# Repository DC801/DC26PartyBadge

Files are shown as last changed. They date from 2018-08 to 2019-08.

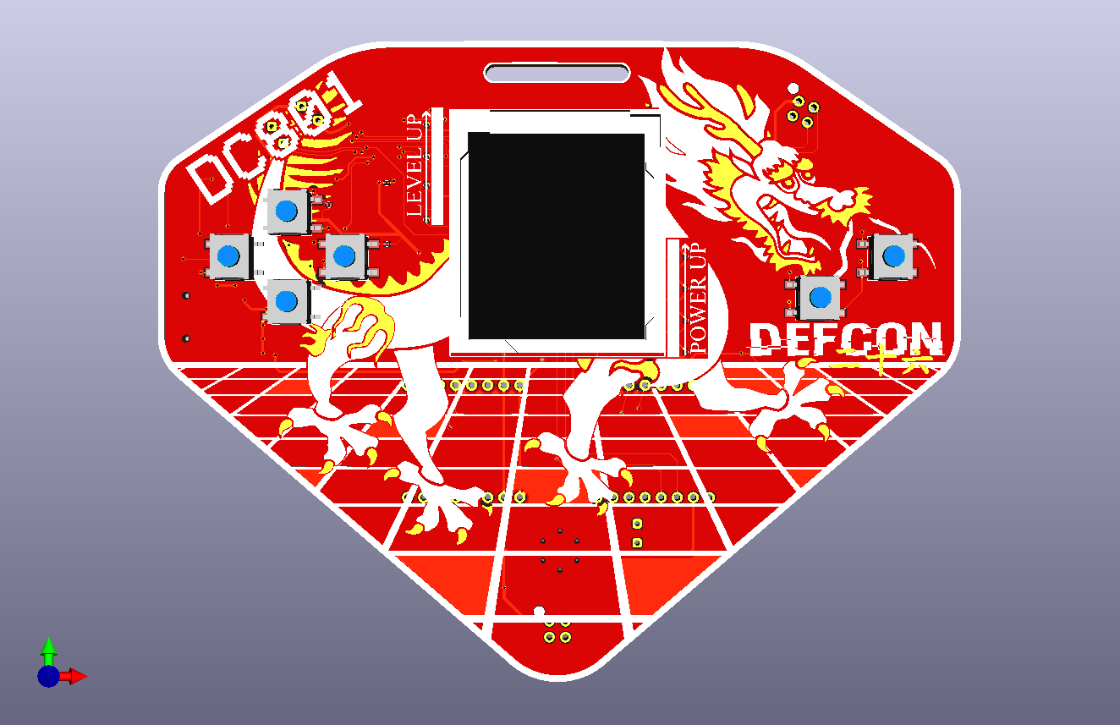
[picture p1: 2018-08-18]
Hardware/images/Dragon-ProtoFinal-Front.png

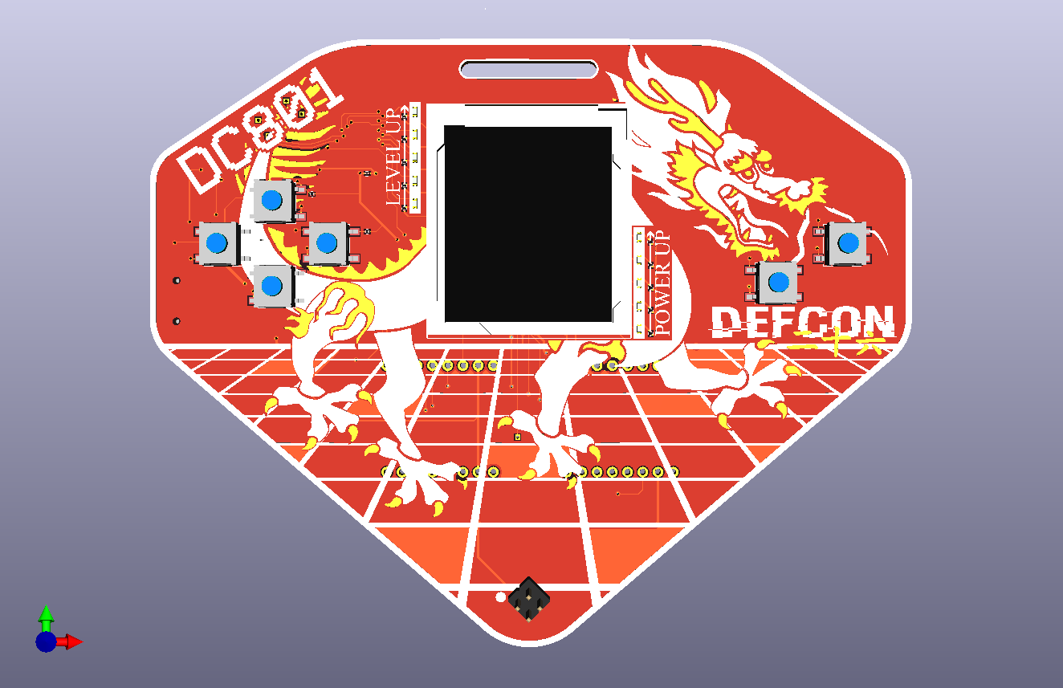
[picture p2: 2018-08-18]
Hardware/images/DragonMockupFront1.png

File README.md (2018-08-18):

# DC801 DC26 Party Badge
Party badge and BLE hardware board

# Hardware
 - **Rigado BMD-300** Bluetooth low energy based on a Nordic nRF52832
   - 16MHz ARM® Cortex™ M4F CPU, 512kB of flash memory, 64kB RAM
   - [https://www.rigado.com/product/bmd-300/](https://www.rigado.com/product/bmd-300/)
 ***
 - **Lots of I/O**
   - Speaker
   - 6 buttons
   - One hidden button
   - SPI LCD screen
   - Selected pin breakouts
   - JTAG interface
   - Micro USB
   - microSD card
   - 2 SAO connectors
   - 2 minibadges
 ***
 - A MCP73831 LiPo battery charger
 - Kickass silkscreen

Board design is in Kicad

See the [Hardware](/Hardware) directory for more info, schematics and etc

# SD Card

Format your SD card as FAT32 and copy the contents of [SD_Card](SD_Card) into it

# Software
 - Environment is GNU ARM GCC with your choice of IDE (I used CLion)
 - Need a J-Link Segger JTAG programmer
 - Uses the softdevice s132

See the [Software](/Software) directory for more info

# What's it do?

Awesome **things**, that's what!  See the [Software](Software) directory for more information.

# More info

Follow [@rushan_ee](http://twitter.com/rushan_ee) or [@hamster](http://twitter.com/hamster) for updates

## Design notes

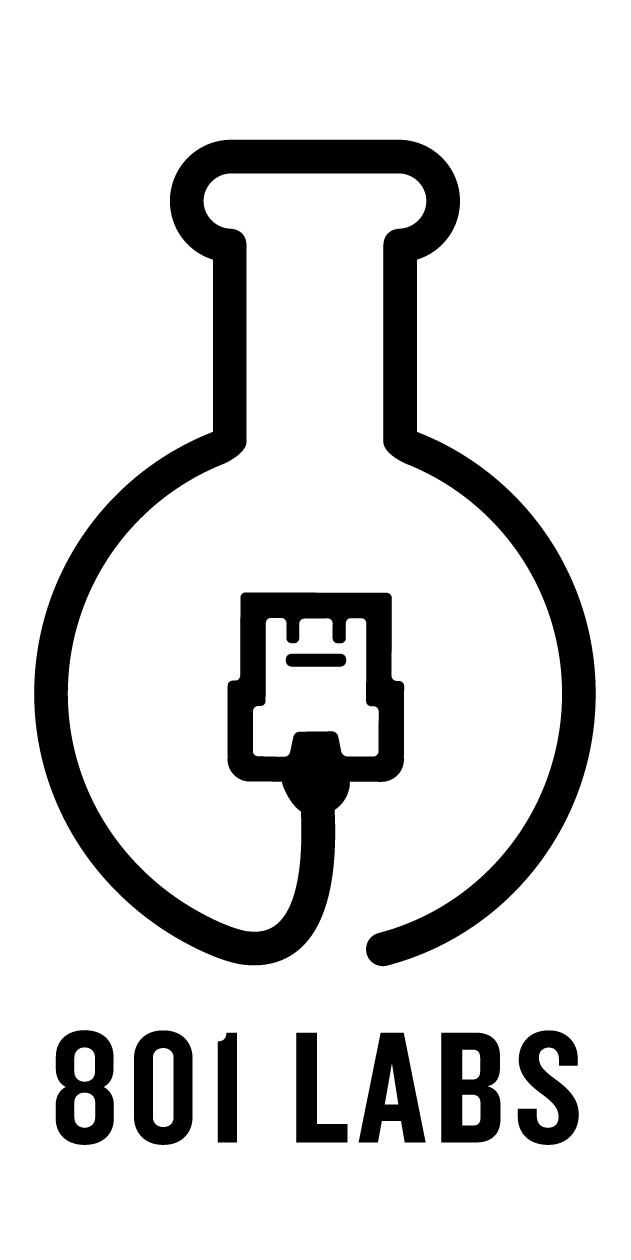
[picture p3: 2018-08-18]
Hardware/images/801LABS-01.png

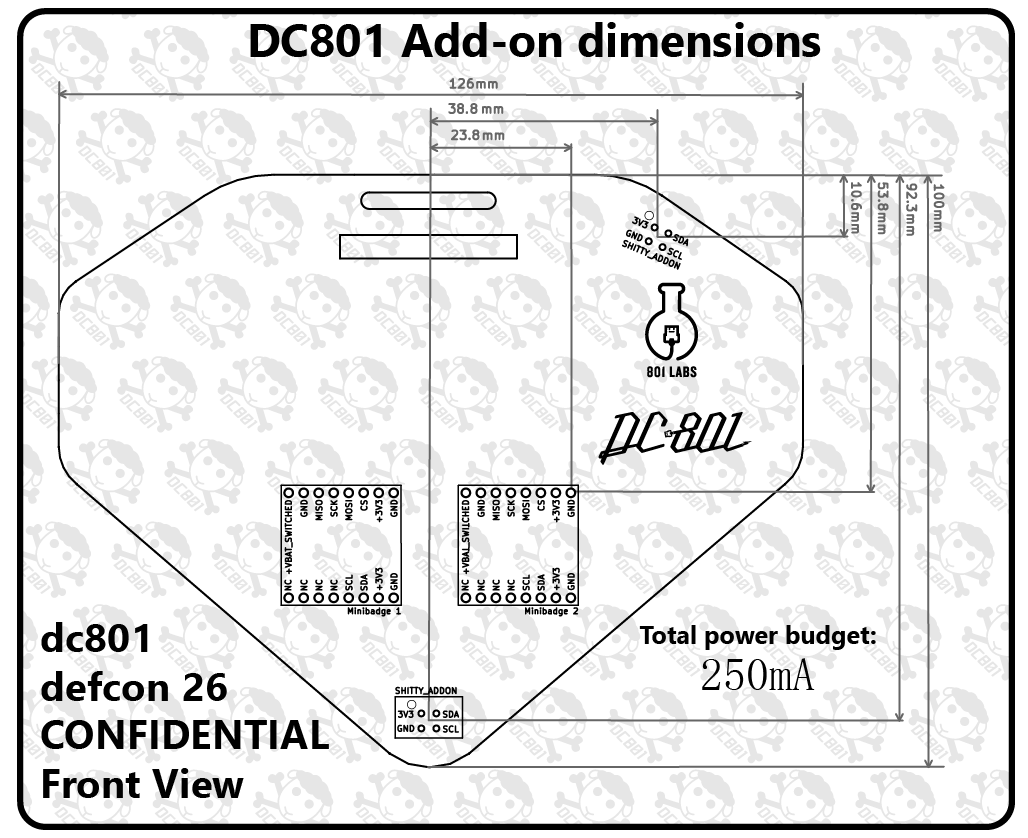
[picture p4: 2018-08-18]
Hardware/images/svg/dc801-dc26-addon-dimensions-01.png

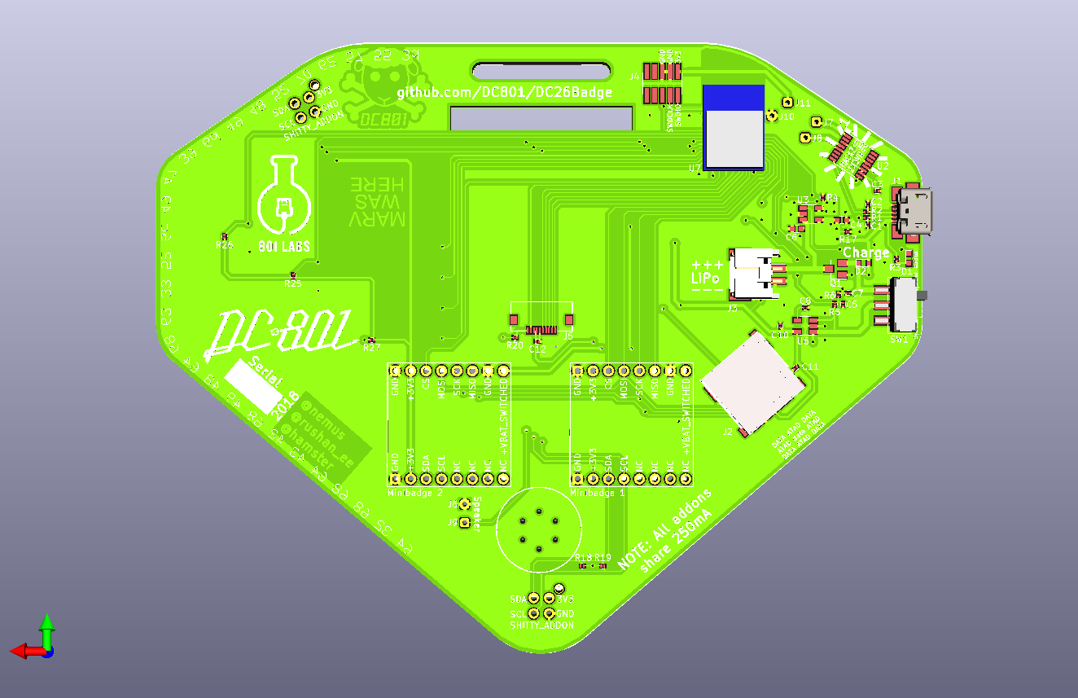
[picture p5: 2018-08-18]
Hardware/images/DragonBoardBack-Final.png

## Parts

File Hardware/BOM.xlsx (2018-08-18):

Ref Des | Description | Mfg Part # | Package | Supplier | Supplier Part # | QTY per badge | Cost ea | Cost badge | Min Qty | Total Needed | Total Cost
U1,U4 - DNS | Minibadge socket
U5 - DNS | Shitty Addon socket
U3 | LiPo charger | MCP73831T-2ACI/OT | SOT-23-5 | Digikey | MCP73831T-2ACI/OTCT-ND | 1 | 0.4452 | 0.4452 |  | 400 | 178.08
U6 | 3.3V Reg 400mA | TPS73633DBVT | SOT95P280X145-5N | Digikey | 296-15819-1-ND | 1 | 1.518 | 1.518 | 250 | 400 | 607.2
U7 | Rigado BMD-300 | BMD-300 | BMD-300 | Digikey | 1604-1006-2-ND | 1 | 7.0623 | 7.0623 | 1000 | 400 | 2824.92
U2 - DNS | FTDI USB to Serial - DNS | FT230XS | SSOP-16 | Digikey | 768-1135-1-ND | 0 | 1.71 | 0 |  | 0 | 0
C5 | 1nF | GRM033R71C102KA01D | 0201 | Digikey | 490-6147-1-ND | 1 | 0.0117 | 0.0117 |  | 400 | 4.68
C3,C7,C8,C9,C10,C11,C12 | 0.1uF Cap | GRM033R60J104KE19D | 0201 | Digikey | 490-3167-1-ND | 5 | 0.0156 | 0.078 |  | 2000 | 31.2
C1,C2 | 47pF Cap | C0201C470J4GAC7867 | 0201 | Digikey | 399-14861-1-ND | 2 | 0.055 | 0.11 |  | 800 | 44
C4,C6 | 4.7uF Cap | C0603C104K9RAC7867 | 0603 | Digikey | 399-15351-1-ND | 2 | 0.1161 | 0.2322 |  | 800 | 92.88
D2 | Schottky diode | SD0603S040S0R2 | 0603 | Digikey | 478-7798-1-ND | 1 | 0.15572 | 0.15572 |  | 400 | 62.288
D1,D3,D4 | Red LED | SML-D12V1WT86 | 0603 | Digikey | SML-D12V1WT86CT-ND | 4 | 0.04007 | 0.16028 | 1000 | 1600 | 64.112
D5,D6,D11 | Yellow LED | SML-D12Y1WT86 | 0603 | Digikey | SML-D12Y1WT86DKR-ND | 3 | 0.04007 | 0.12021 | 1000 | 1200 | 48.084
D8,D9,D10 | Green LED | SML-D12M1WT86 | 0603 | Digikey | SML-D12M1WT86DKR-ND | 4 | 0.04007 | 0.16028 | 1000 | 1600 | 64.112
Q1 | FDN360P | FDN360P | SuperSOT-3 | Digikey | FDN360PCT-ND | 1 | 0.2943 | 0.2943 |  | 400 | 117.72
R17,R21,R22,R23,R24,R25,R26 | 10k resistor | RMCF0201JG10K0 | 0201 | Digikey | RMCF0201JG10K0CT-ND | 7 | 0.0086 | 0.0602 |  | 2800 | 24.08
R1,R2 | 27R resistor | RMCF0201FT27R0 | 0201 | Digikey | RMCF0201FT27R0CT-ND | 2 | 0.0114 | 0.0228 |  | 800 | 9.12
R3 | 470R resistor | RMCF0201JT470R | 0201 | Digikey | RMCF0201JT470RCT-ND | 1 | 0.0086 | 0.0086 |  | 400 | 3.44
R4 | 2k resistor | RMCF0201JT2K00 | 0201 | Digikey | RMCF0201JT2K00CT-ND | 1 | 0.0158 | 0.0158 |  | 400 | 6.32
R7,R8,R9,R10,R12,R13,R14,R15 | 75R resistor | RC0201JR-0775RL | 0201 | Digikey | YAG2929CT-ND | 10 | 0.0132 | 0.132 |  | 4000 | 52.8
R18,R19 | 4.7k resistor | RMCF0201JT4K70 | 0201 | Digikey | RMCF0201JT4K70CT-ND | 2 | 0.0158 | 0.0316 |  | 800 | 12.64
R27 | 10M resistor | RMCF0201JT10M0 | 0201 | Digikey | RMCF0201JT10M0CT-ND | 1 | 0.0086 | 0.0086 |  | 400 | 3.44
R20 | 33R resistor | RMCF0201FT33R0 | 0201 | Digikey | RMCF0201FT33R0CT-ND | 1 | 0.0114 | 0.0114 |  | 400 | 4.56
R5 | 806k resistor | RMCF0201FT806K | 0201 | Digikey | RMCF0201FT806KCT-ND | 1 | 0.0222 | 0.0222 |  | 400 | 8.88
R6 | 2M resistor | RC0201JR-072ML | 0201 | Digikey | YAG2885CT-ND | 1 | 0.0132 | 0.0132 |  | 400 | 5.28
J3 | JST 2mm male | S2B-PH-SM4-TB(LF)(SN) |  | Digikey | 455-1749-1-ND | 1 |  | 0 |  | 400 | 0
J2 | MicroSD socket | 114-00841-68 |  | Digikey | 114-00841-68-1-ND | 1 | 1.05336 | 1.05336 |  | 400 | 421.344
J1 | Micro USB | 10118192-0001LF |  | Digikey | 609-4613-1-ND | 1 | 0.27444 | 0.27444 |  | 400 | 109.776
J4 | JTAG, dual row 1.27mm | 3220-10-0300-00 |  | Digikey | 1175-1629-ND | 1 | 0.437 | 0.437 | 100 | 400 | 174.8
J5 | FFC/FPC LCD connector | XF2L-1035-1A |  | Digikey | Z5306CT-ND | 1 | 0.9751 | 0.9751 | 100 | 400 | 390.04
SW1 | Power Switch | JS102011SAQN |  | Digikey | 401-1999-1-ND | 1 | 0.43692 | 0.43692 |  | 400 | 174.768
SW2,SW3,SW4,SW5,SW6,SW7 | Pushbuttons | PTS645SM43SMTR92 LFS |  | Digikey | CKN9112TR-ND | 6 | 0.08614 | 0.51684 | 1000 | 2400 | 206.736
SW8 - DNS | Capacitive button |  |  |  |  | 0 | 0 | 0 |  | 0 | 0
Speaker - DNS | 8 ohm speaker | SP-1504 |  | Digikey | 433-1106-ND | 1 | 1.232 | 1.232 |  | 400 | 492.8
LCD - DNS | CFAF128128B-0145T |  |  |  |  | 1 |  | 0 |  | 400 | 0
 |  |  |  |  |  | 67 |  |  | Total | 26800 | 6240.1
 |  |  |  |  |  |  | Badges |  | Purpose | Color | Qty
 |  |  |  |  |  |  |  |  | Prototype | Red | 10
 |  |  |  |  |  |  |  |  | Party | Blue | 190
 |  |  |  |  |  |  |  |  | Other | Green | 200
 |  |  |  |  |  |  |  |  | Total |  | 400

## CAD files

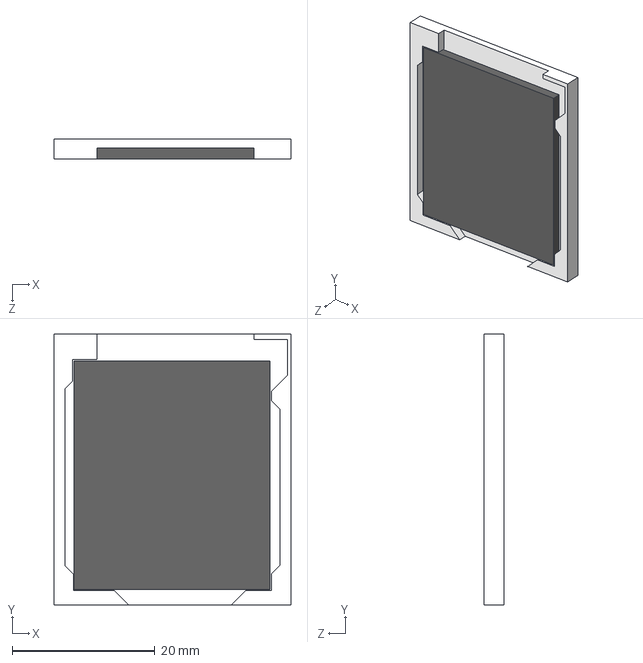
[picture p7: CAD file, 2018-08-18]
Hardware/3d/LCD Display.STEP
33.2 x 38.0 x 2.75 mm

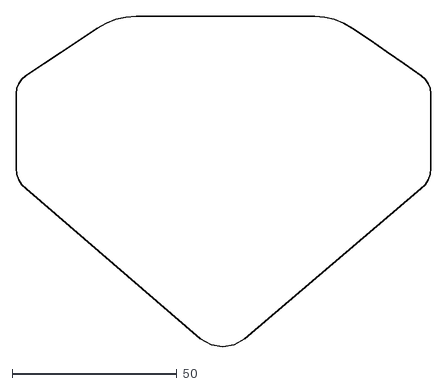
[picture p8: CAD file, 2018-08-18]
Hardware/images/DragonOutline.dxf
126.0 x 100.4

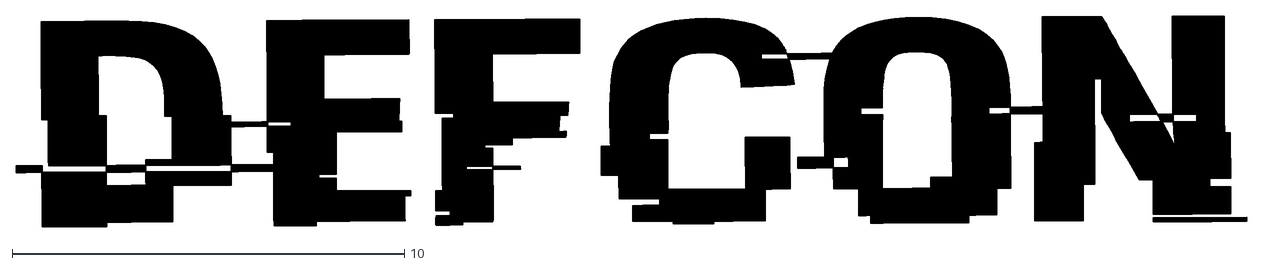
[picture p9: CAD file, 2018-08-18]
Hardware/images/defcon.dxf
31.4 x 5.37

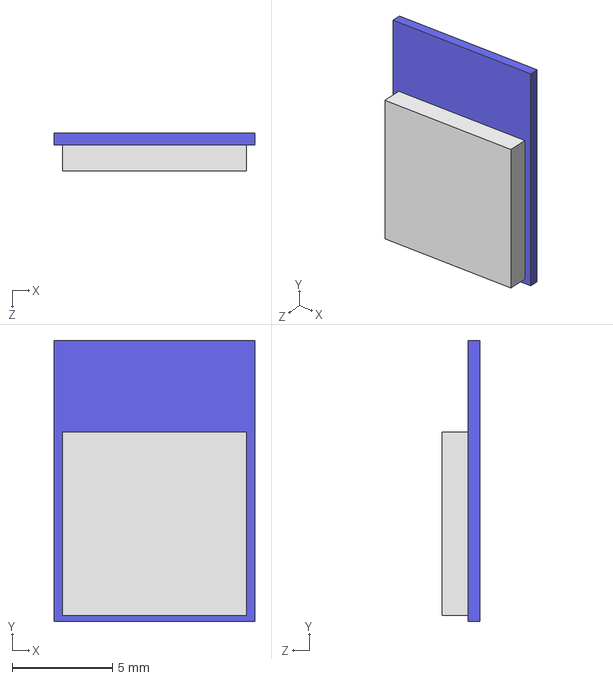
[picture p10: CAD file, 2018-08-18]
Hardware/3d/BMD-300.STEP
10.0 x 14.0 x 1.90 mm

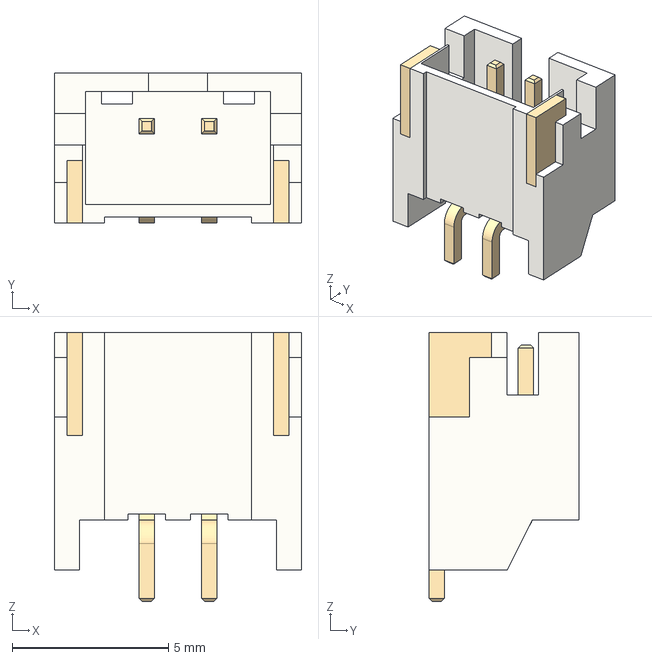
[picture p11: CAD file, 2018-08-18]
Hardware/3d/S2B-PH-SM4-TB.stp
7.90 x 4.80 x 8.60 mm

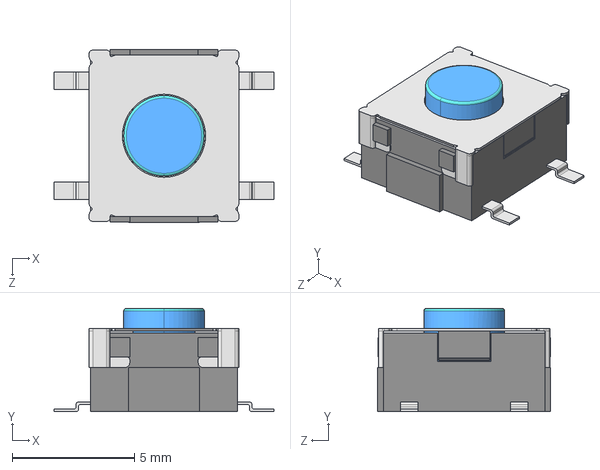
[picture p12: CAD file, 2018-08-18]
Hardware/3d/01_tactile_push_boton_B3S-1000_newark_52F3560.STEP
9.00 x 4.23 x 7.08 mm

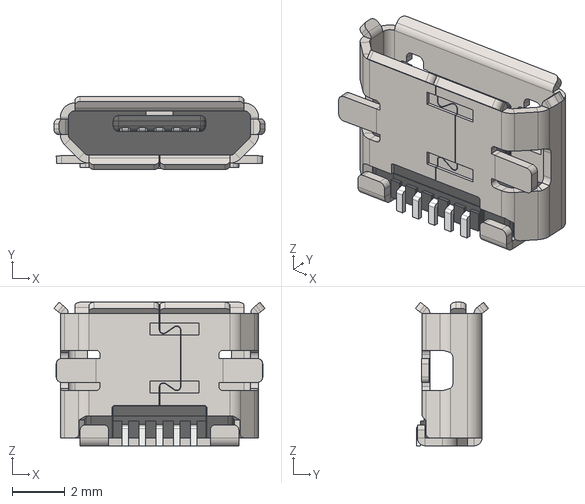
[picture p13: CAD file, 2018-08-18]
Hardware/3d/molex_0473460001.STEP
7.98 x 2.76 x 5.43 mm

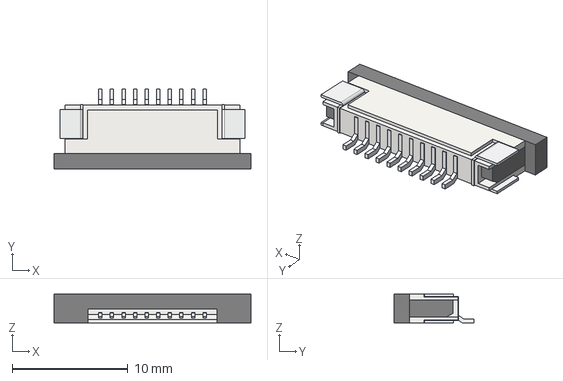
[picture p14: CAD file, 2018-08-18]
Hardware/3d/FFC3B05-10-T.step
17.0 x 6.90 x 2.50 mm

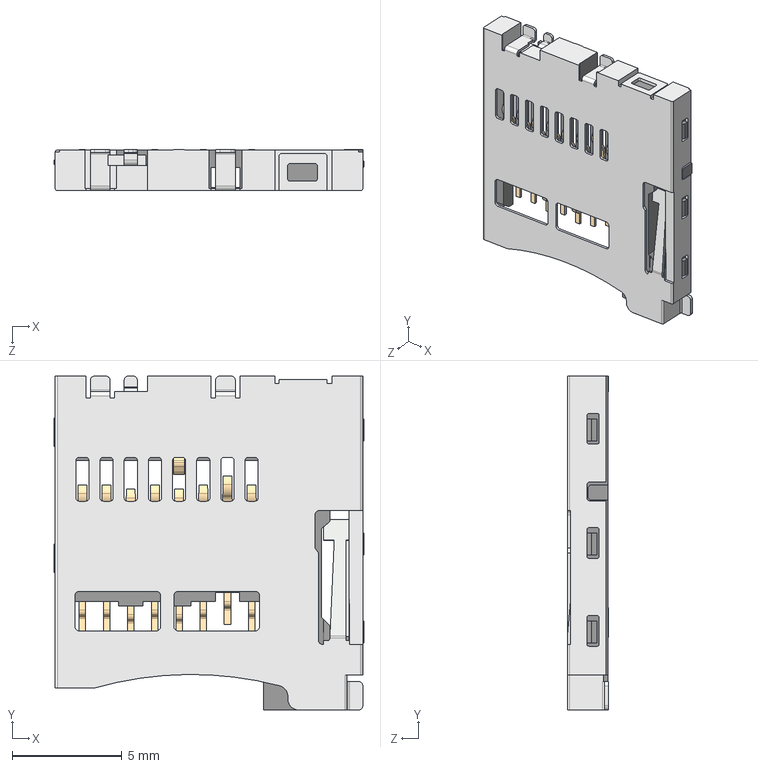
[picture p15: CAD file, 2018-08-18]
Hardware/3d/473521001_microSD.step
14.1 x 15.2 x 1.88 mm

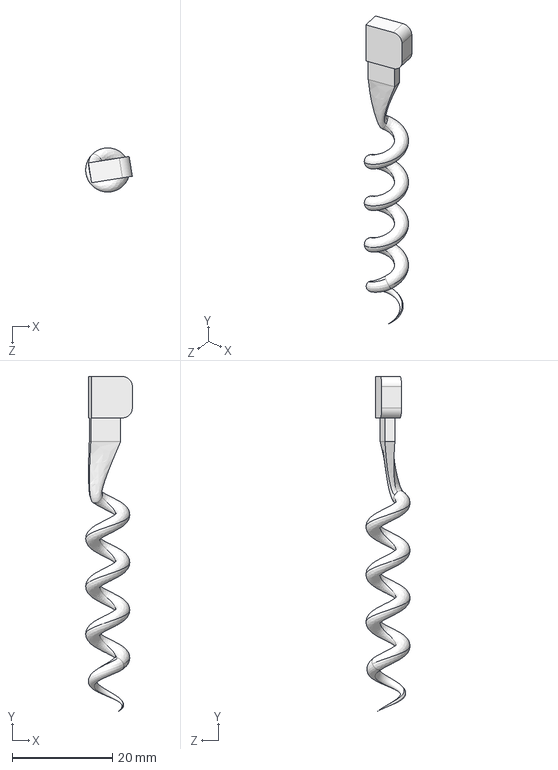
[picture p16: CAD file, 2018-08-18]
Hardware/3d/CorkScrew.STEP
9.30 x 66.8 x 8.80 mm

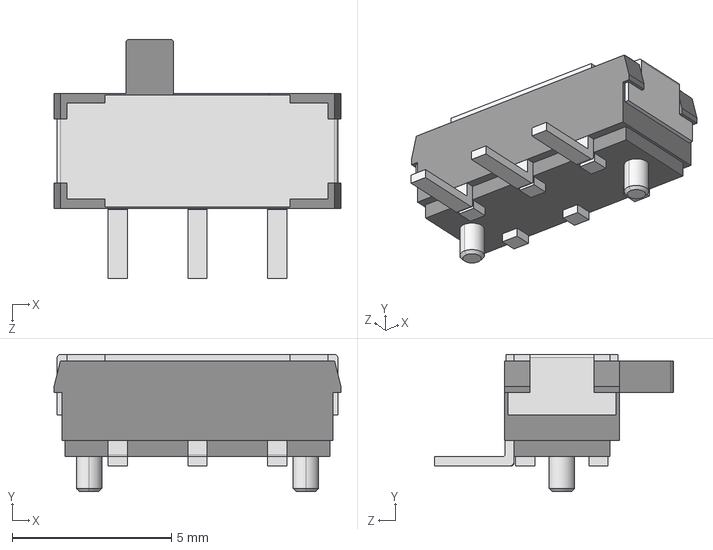
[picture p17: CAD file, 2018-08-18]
Hardware/3d/JS102011SAQN.STEP
9.00 x 4.30 x 7.50 mm

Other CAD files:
Hardware/3d/01_tactile_push_boton_B3S-1000_newark_52F3560.SLDPRT
Hardware/3d/BMD-300.SLDPRT
Hardware/3d/LCD Display.SLDPRT

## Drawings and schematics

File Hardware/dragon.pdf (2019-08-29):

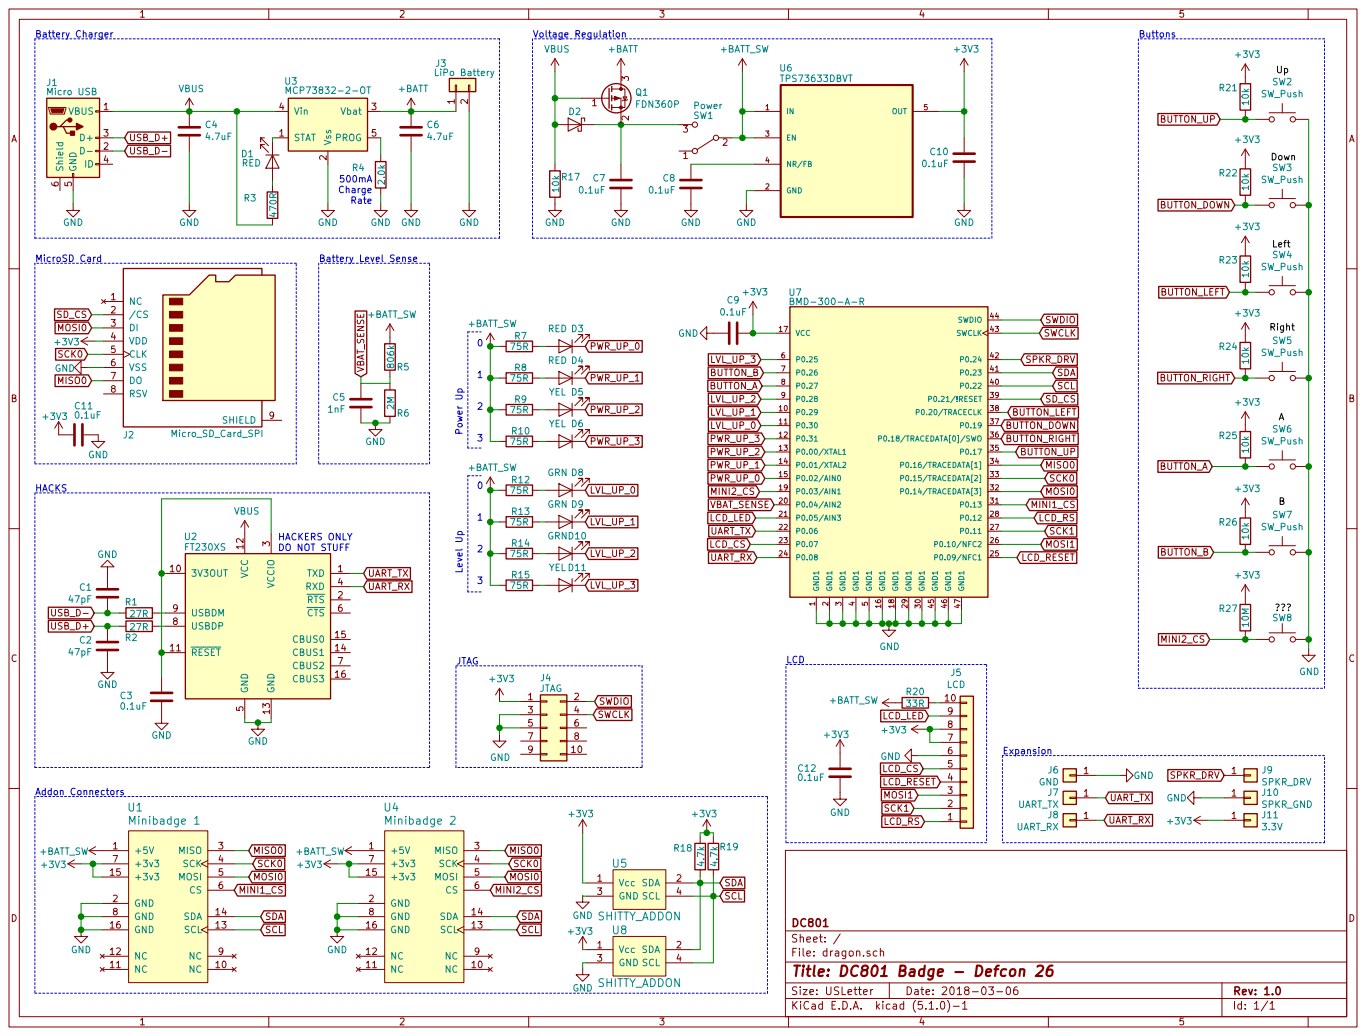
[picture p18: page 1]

5 P0.28 9 P0.29 10 P0.30 11 P0.31 12 VCC 17 P0.19 37 P0.20/TRACECLK 38 P0.21/!RESET 39 P0.22 40 P0.23 41 P0.24 42 SWCLK 43 P0.25 6 P0.26 7 P0.27 8 U7BMD-300-A-R GND

3 GND1 30 P0.13 31 P0.14/TRACEDATA[3] 32 P0.15/TRACEDATA[2] 33 P0.16/TRACEDATA[1] 34 P0.17 35 P0.18/TRACEDATA[0]/SWO 36 GND1
File: dragon.sch Sheet: / DC801GND1

Id: 1/1 Title: DC801 Badge - Defcon 26

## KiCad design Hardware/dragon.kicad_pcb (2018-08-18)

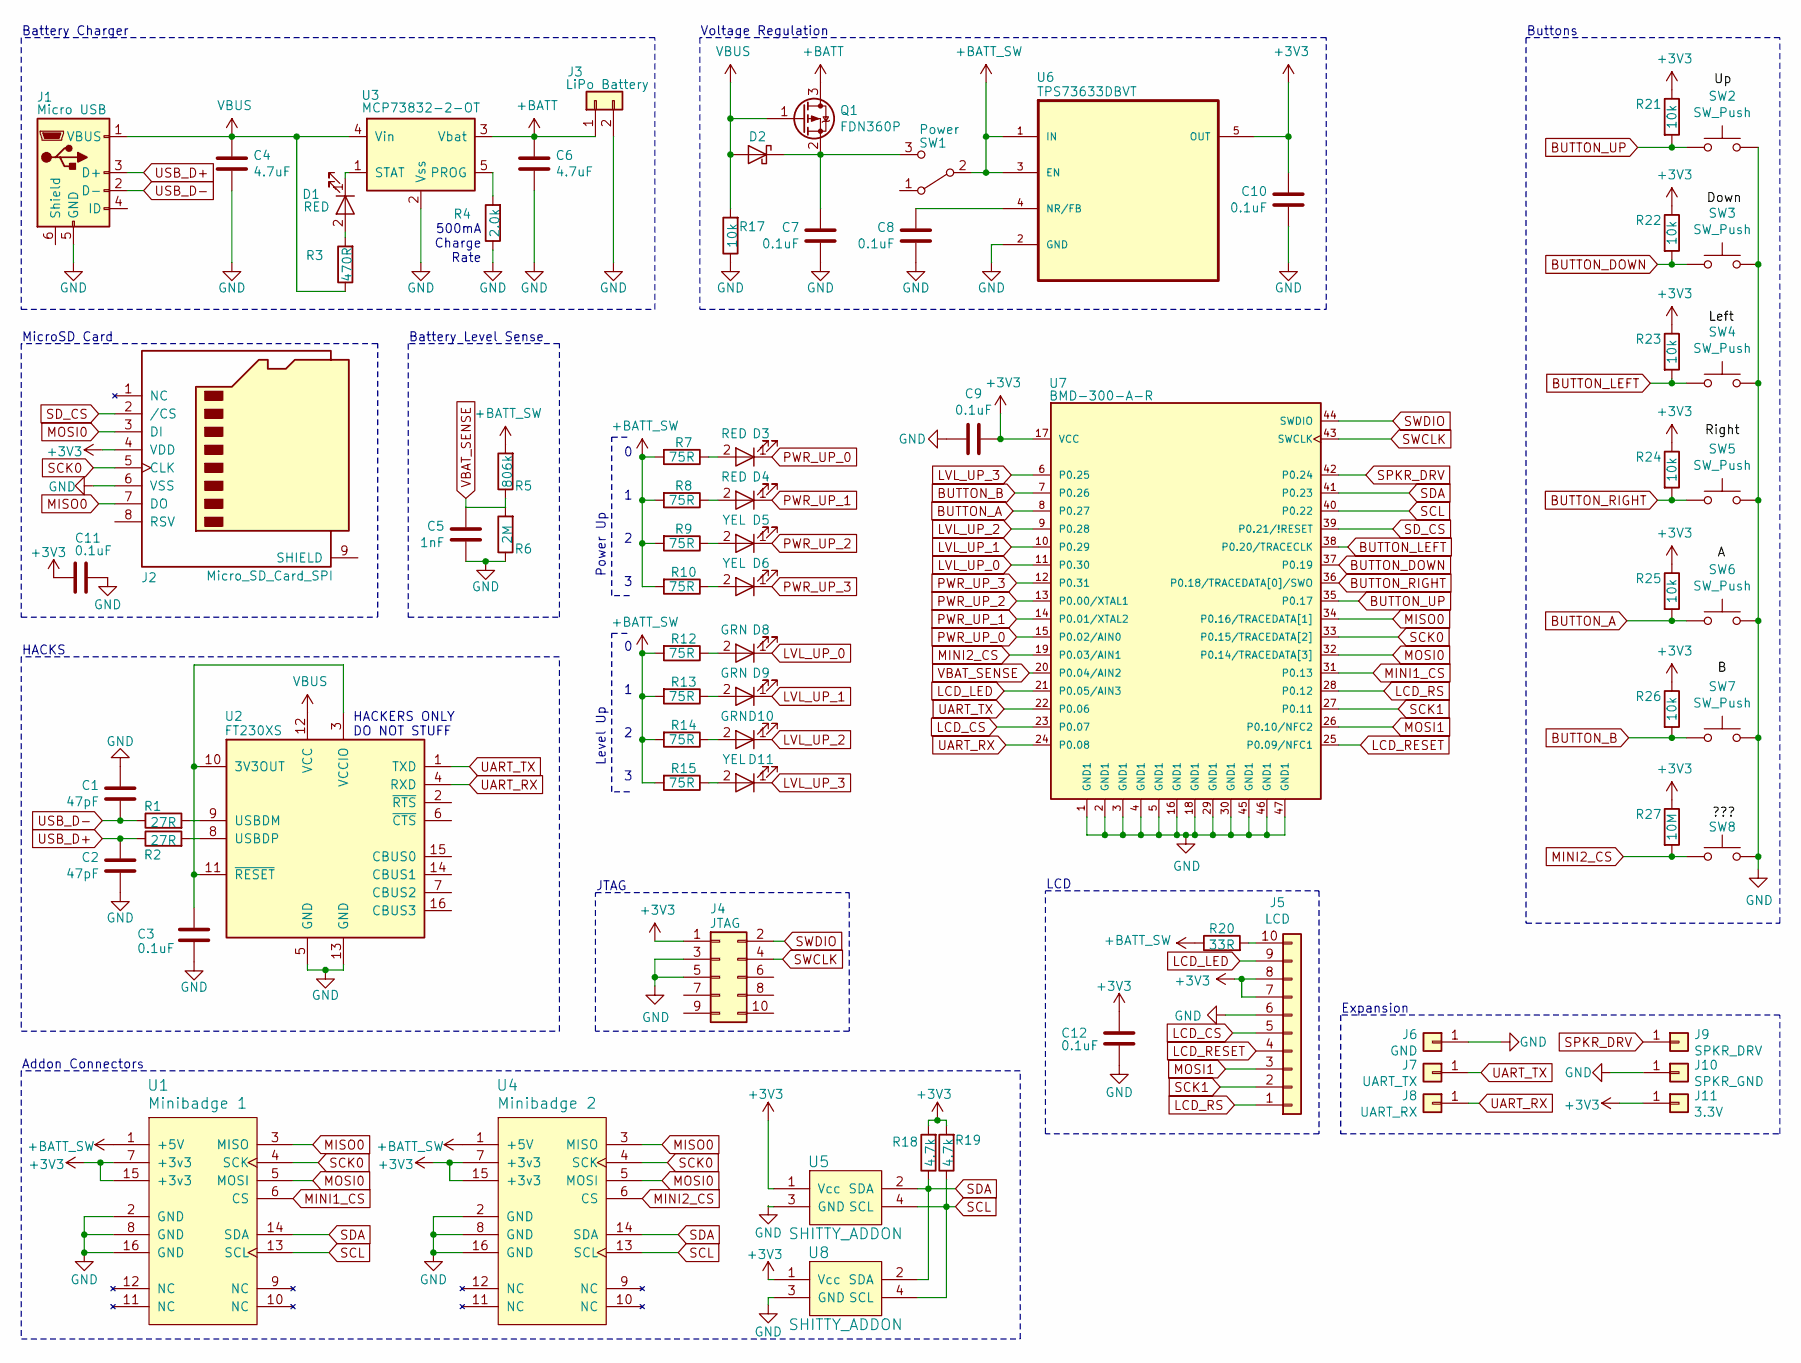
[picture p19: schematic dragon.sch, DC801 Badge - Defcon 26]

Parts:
C1, C2: 47pF; C_0201
C3, C7, C8, C9, C10, C11, C12: 0.1uF; C_0201
C4, C6: 4.7uF; C_0603
C5: 1nF; C_0201
D1, D3, D4: RED; LED_0603
D2: D_Schottky; D_0603
D5, D6, D11: YEL; LED_0603
D8, D9, D10: GRN; LED_0603
J1: Micro USB; MicroUSB-10118192-0001LF
J2: Micro_SD_Card_SPI; MicroSD-Socket-1140084168
J3: LiPo Battery; JST_PH_S2B-PH-SM4-TB_02x2.00mm_Angled
J4: JTAG; Pin_Header_Straight_2x05_Pitch1.27mm_SMD
J5: LCD; XF2L-1035-1A
J6: GND; SolderWirePad_single_0-8mmDrill
J7: UART_TX; SolderWirePad_single_0-8mmDrill
J8: UART_RX; SolderWirePad_single_0-8mmDrill
J9: SPKR_DRV; SolderWirePad_single_0-8mmDrill
J10: SPKR_GND; SolderWirePad_single_0-8mmDrill
J11: 3.3V; SolderWirePad_single_0-8mmDrill
Q1: FDN360P; SuperSOT-3
R1, R2: 27R; R_0201
R3: 470R; R_0201
R4: 2.0k; R_0201
R5: 806k; R_0201
R6: 2M; R_0201
R7, R8, R9, R10, R12, R13, R14, R15: 75R; R_0201
R17, R21, R22, R23, R24, R25, R26: 10k; R_0201
R18, R19: 4.7k; R_0201
R20: 33R; R_0201
R27: 10M; R_0201
SW1: Power; SW_SPDT_CK-JS102011SAQN
SW2, SW3, SW4, SW5, SW6, SW7: SW_Push; SW_SPST_B3S-1000
SW8: TEST_2P; Test_Point_2Pads
U1: Minibadge 1; SAINTCON-Minibadge
U2: FT230XS; SSOP-16_3.9x4.9mm_Pitch0.635mm
U3: MCP73832-2-OT; TSOT-23-5
U4: Minibadge 2; SAINTCON-Minibadge
U5, U8: SHITTY_ADDON; Badgelife-Shitty-2x2-NotRotated
U6: TPS73633DBVT; TSOT-23-5
U7: BMD-300-A-R; RIGADO_BMD-300-A-R

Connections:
+3V3: C9.1, C10.1, C11.2, C12.2, J2.4 (VDD), J4.1, J5.7, J5.8, J11.1, R18.2, R19.2, R21.1, R22.1, R23.1, R24.1, R25.1, R26.1, R27.1, U1.7 (+3v3), U1.15 (+3v3), U4.7 (+3v3), U4.15 (+3v3), U5.1 (Vcc), U6.5 (OUT), U7.17 (VCC), U8.1 (Vcc)
+BATT: C6.2, J3.1, Q1.3 (D), U3.3 (Vbat)
+BATT_SW: R5.2, R7.2, R8.2, R9.2, R10.2, R12.2, R13.2, R14.2, R15.2, R20.1, SW1.2 (B), U1.1 (+5V), U4.1 (+5V), U6.1 (IN), U6.3 (EN)
BUTTON_A: R25.2, SW6.1, U7.8 (P0.27)
BUTTON_B: R26.2, SW7.1, U7.7 (P0.26)
BUTTON_DOWN: R22.2, SW3.1, U7.37 (P0.19)
BUTTON_LEFT: R23.2, SW4.1, U7.38 (P0.20/TRACECLK)
BUTTON_RIGHT: R24.2, SW5.1, U7.36 (P0.18/TRACEDATA[0]/SWO)
BUTTON_UP: R21.2, SW2.1, U7.35 (P0.17)
GND: C1.1, C2.2, C3.1, C4.1, C5.2, C6.1, C7.2, C8.2, C9.2, C10.2, C11.1, C12.1, J1.5 (GND), J2.6 (VSS), J3.2, J4.3, J4.5, J5.6, J6.1, J10.1, R4.1, R6.1, R17.1, SW2.2, SW3.2, SW4.2, SW5.2, SW6.2, SW7.2, SW8.2, U1.2 (GND), U1.8 (GND), U1.16 (GND), U2.5 (GND), U2.13 (GND), U3.2 (Vss), U4.2 (GND), U4.8 (GND), U4.16 (GND), U5.3 (GND), U6.2 (GND), U7.1 (GND1), U7.2 (GND1), U7.3 (GND1), U7.4 (GND1), U7.5 (GND1), U7.16 (GND1), U7.18 (GND1), U7.29 (GND1), U7.30 (GND1), U7.45 (GND1), U7.46 (GND1), U7.47 (GND1), U8.3 (GND)
LCD_CS: J5.5, U7.23 (P0.07)
LCD_LED: J5.9, U7.21 (P0.05/AIN3)
LCD_RESET: J5.4, U7.25 (P0.09/NFC1)
LCD_RS: J5.1, U7.28 (P0.12)
LVL_UP_0: D8.1 (K), U7.11 (P0.30)
LVL_UP_1: D9.1 (K), U7.10 (P0.29)
LVL_UP_2: D10.1 (K), U7.9 (P0.28)
LVL_UP_3: D11.1 (K), U7.6 (P0.25)
MINI1_CS: U1.6 (CS), U7.31 (P0.13)
MINI2_CS: R27.2, SW8.1, U4.6 (CS), U7.19 (P0.03/AIN1)
MISO0: J2.7 (DO), U1.3 (MISO), U4.3 (MISO), U7.34 (P0.16/TRACEDATA[1])
MOSI0: J2.3 (DI), U1.5 (MOSI), U4.5 (MOSI), U7.32 (P0.14/TRACEDATA[3])
MOSI1: J5.3, U7.26 (P0.10/NFC2)
unnamed: C3.2, U2.3 (VCCIO), U2.10 (3V3OUT), U2.11 (~RESET)
unnamed: C7.1, D2.1 (K), Q1.2 (S), SW1.3 (C)
unnamed: C8.1, U6.4 (NR/FB)
unnamed: D1.1 (K), U3.1 (STAT)
unnamed: D1.2 (A), R3.2
unnamed: D3.2 (A), R7.1
unnamed: D4.2 (A), R8.1
unnamed: D5.2 (A), R9.1
unnamed: D6.2 (A), R10.1
unnamed: D8.2 (A), R12.1
unnamed: D9.2 (A), R13.1
unnamed: D10.2 (A), R14.1
unnamed: D11.2 (A), R15.1
unnamed: J5.10, R20.2
unnamed: R1.2, U2.9 (USBDM)
unnamed: R2.2, U2.8 (USBDP)
unnamed: R4.2, U3.5 (PROG)
PWR_UP_0: D3.1 (K), U7.15 (P0.02/AIN0)
PWR_UP_1: D4.1 (K), U7.14 (P0.01/XTAL2)
PWR_UP_2: D5.1 (K), U7.13 (P0.00/XTAL1)
PWR_UP_3: D6.1 (K), U7.12 (P0.31)
SCK0: J2.5 (CLK), U1.4 (SCK), U4.4 (SCK), U7.33 (P0.15/TRACEDATA[2])
SCK1: J5.2, U7.27 (P0.11)
SCL: R19.1, U1.13 (SCL), U4.13 (SCL), U5.4 (SCL), U7.40 (P0.22), U8.4 (SCL)
SDA: R18.1, U1.14 (SDA), U4.14 (SDA), U5.2 (SDA), U7.41 (P0.23), U8.2 (SDA)
SD_CS: J2.2 (/CS), U7.39 (P0.21/!RESET)
SPKR_DRV: J9.1, U7.42 (P0.24)
SWCLK: J4.4, U7.43 (SWCLK)
SWDIO: J4.2, U7.44 (SWDIO)
UART_RX: J8.1, U2.4 (RXD), U7.24 (P0.08)
UART_TX: J7.1, U2.1 (TXD), U7.22 (P0.06)
USB_D+: C2.1, J1.3 (D+), R2.1
USB_D-: C1.2, J1.2 (D-), R1.1
VBAT_SENSE: C5.1, R5.1, R6.2, U7.20 (P0.04/AIN2)
VBUS: C4.2, D2.2 (A), J1.1 (VBUS), Q1.1 (G), R3.1, R17.2, U2.12 (VCC), U3.4 (Vin)

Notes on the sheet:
Power Up
Level Up
500mA Charge Rate
Buttons
LCD
Voltage Regulation
Battery Charger
MicroSD Card
Battery Level Sense
HACKS
HACKERS ONLY DO NOT STUFF
Addon Connectors
Expansion
JTAG

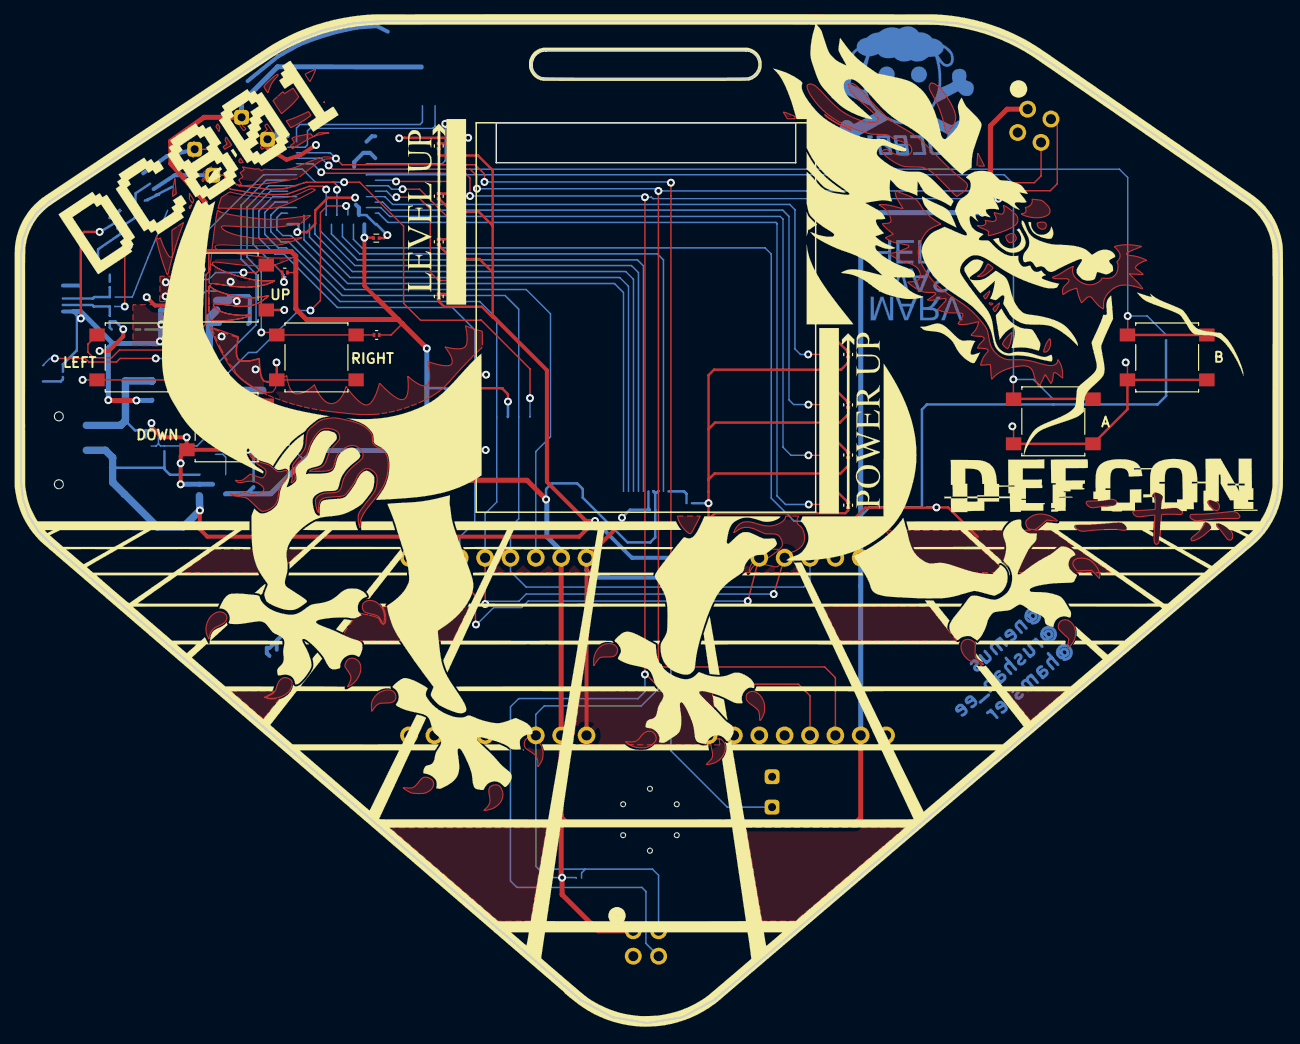
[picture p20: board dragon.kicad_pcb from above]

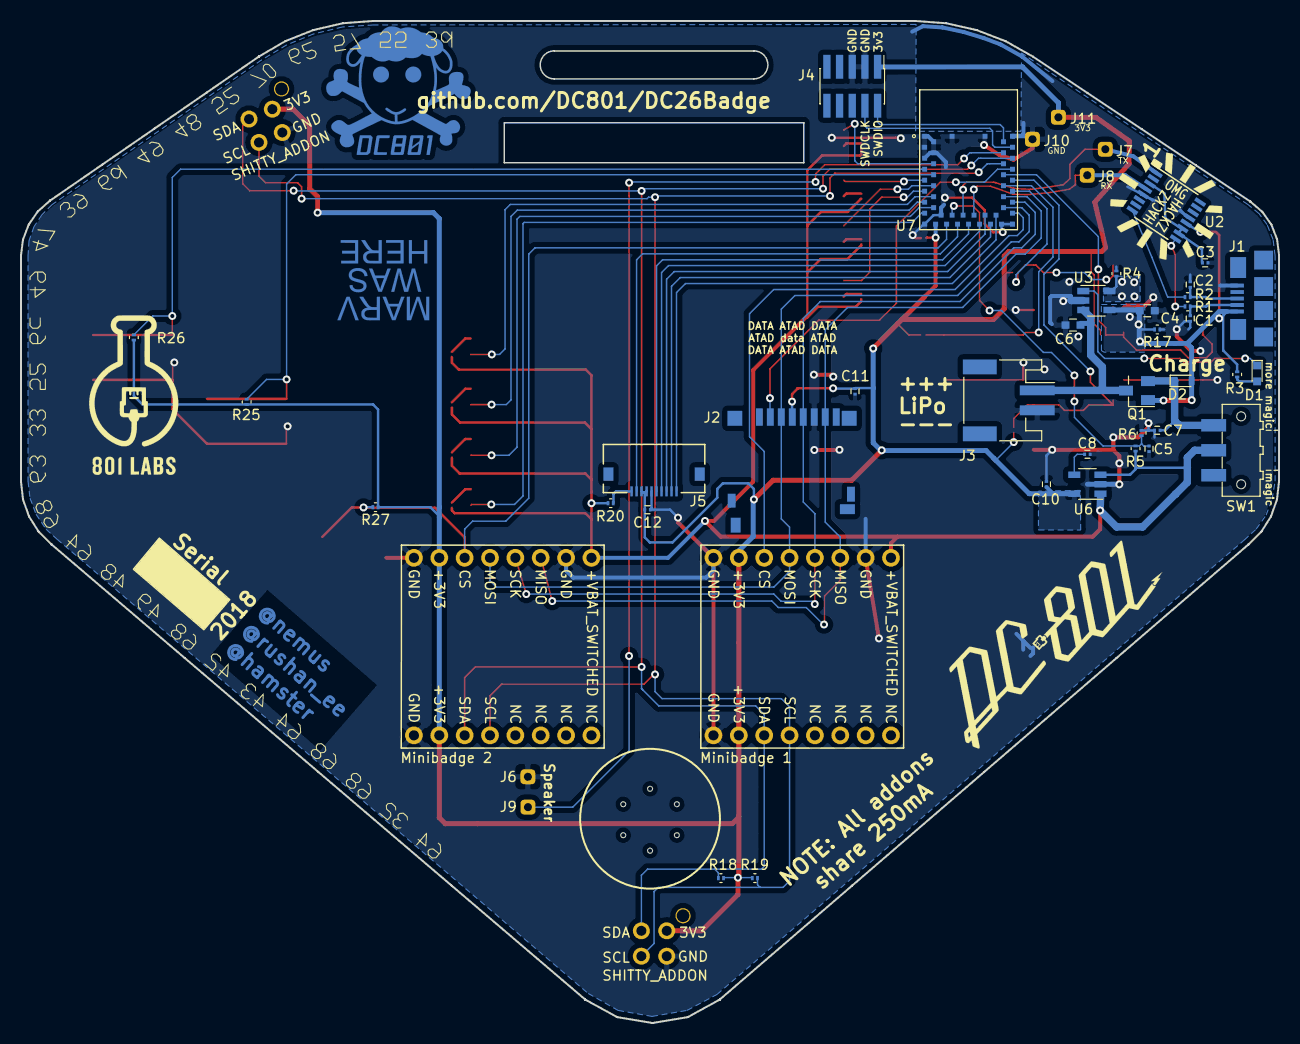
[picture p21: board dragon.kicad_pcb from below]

Board: 2 copper layers, 126.0 x 100.4 mm, 74 parts (43 on the bottom side), 58 nets.

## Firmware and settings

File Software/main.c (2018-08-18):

/**
 *
 * @file main.c
 *
 * @date May 24, 2017
 * @author hamster
 *
 * @brief This is the entry point for the DC801 DC26 party badge
 *
 */

#include <stdint.h>
#include "common.h"
#include "user.h"

volatile bool partyMode = false;
volatile bool sheepMode = false;

APP_TIMER_DEF(standby_animation_timer_id);

static void standby_animation_timeout_handler(void *p_context) {
    UNUSED_PARAMETER(p_context);

    util_gfx_draw_raw_file_stop();
}

/**
 * Initialize the LEDs
 *
 * LED_POWER_UP_2 is not used because there is some bug in the softdevice where it realllllly
 * wants to flash that LED on LCD SPI access and it's just annoying.  So, we'll just disabled.
 */
static void led_init(void){
    // Setup and turn off the LEDs
    nrf_gpio_cfg_output(LED_LEVEL_UP_0);
    nrf_gpio_cfg_output(LED_LEVEL_UP_1);
    nrf_gpio_cfg_output(LED_LEVEL_UP_2);
    nrf_gpio_cfg_output(LED_LEVEL_UP_3);
    nrf_gpio_cfg_output(LED_POWER_UP_0);
    nrf_gpio_cfg_output(LED_POWER_UP_1);
    //nrf_gpio_cfg_output(LED_POWER_UP_2);
    nrf_gpio_cfg_output(LED_POWER_UP_3);

    nrf_gpio_pin_set(LED_LEVEL_UP_0);
    nrf_gpio_pin_set(LED_LEVEL_UP_1);
    nrf_gpio_pin_set(LED_LEVEL_UP_2);
    nrf_gpio_pin_set(LED_LEVEL_UP_3);
    nrf_gpio_pin_set(LED_POWER_UP_0);
    nrf_gpio_pin_set(LED_POWER_UP_1);
    nrf_gpio_pin_set(LED_POWER_UP_2);
    nrf_gpio_pin_set(LED_POWER_UP_3);
}

/**
 * Initialize the buttons
 */
static void button_init(void){
    // Setup the buttons
    nrf_gpio_cfg_input(USER_BUTTON_UP, NRF_GPIO_PIN_NOPULL);
    nrf_gpio_cfg_input(USER_BUTTON_DOWN, NRF_GPIO_PIN_NOPULL);
    nrf_gpio_cfg_input(USER_BUTTON_LEFT, NRF_GPIO_PIN_NOPULL);
    nrf_gpio_cfg_input(USER_BUTTON_RIGHT, NRF_GPIO_PIN_NOPULL);
    nrf_gpio_cfg_input(USER_BUTTON_A, NRF_GPIO_PIN_NOPULL);
    nrf_gpio_cfg_input(USER_BUTTON_B, NRF_GPIO_PIN_NOPULL);
}

/**
 * Initialize the speaker
 */
static void speaker_init(void){
    // Setup the beeper
    nrf_gpio_cfg_output(SPEAKER);
}

/**
 * Initialize the logging backend for logging over JTAG
 */
static void log_init(void){
    ret_code_t err_code = NRF_LOG_INIT(NULL);
    APP_ERROR_CHECK(err_code);

    NRF_LOG_DEFAULT_BACKENDS_INIT();
}

/**
 * Handler to show the LEDs during bootup animation
 * @param frame
 * @param p_data
 */
static void bootCallback(uint8_t frame, void *p_data){

    if(frame > 50){
        nrf_gpio_pin_clear(LED_LEVEL_UP_0);
    }
    if(frame > 100){
        nrf_gpio_pin_clear(LED_LEVEL_UP_1);
    }
    if(frame > 150){
        nrf_gpio_pin_clear(LED_LEVEL_UP_2);
    }
    if(frame > 200){
        nrf_gpio_pin_clear(LED_LEVEL_UP_3);
    }

    if(frame > 205){
        nrf_gpio_pin_clear(LED_POWER_UP_0);
    }
    if(frame > 210){
        nrf_gpio_pin_clear(LED_POWER_UP_1);
    }
    if(frame > 215){
        nrf_gpio_pin_clear(LED_POWER_UP_2);
    }
    if(frame > 222){
        nrf_gpio_pin_clear(LED_POWER_UP_3);
    }

}

/**
 * Handler to show the LED blink during party mode
 * @param frame
 * @param p_data
 */
static void partyCallback(uint8_t frame, void *p_data){

    if(frame % 8 == 0){
        setLevelLEDs(LEVEL4);
    }
    else{
        setLevelLEDs(LEVEL0);
    }

    if(frame % 2 == 0){
        setPowerUpLEDs(POWERUP_0);
        nrf_gpio_pin_clear(LED_POWER_UP_0);
    }
    if(frame % 3 == 0){
        setPowerUpLEDs(POWERUP_0);
        nrf_gpio_pin_clear(LED_POWER_UP_1);
    }
    if(frame % 4 == 0){
        setPowerUpLEDs(POWERUP_0);
        nrf_gpio_pin_clear(LED_POWER_UP_3);
    }
    if(frame == 0){
        setPowerUpLEDs(POWERUP_0);
    }


}

typedef enum {
    item_games,
    item_nearby,
    item_extras,
    item_credits,
    item_godmode,
    NUM_MENU_MAIN_ITEMS
} MENU_MAIN;


MENU mainMenu[NUM_MENU_MAIN_ITEMS] = {
        { item_games, "Games" },
        { item_nearby, "Nearby" },
        { item_extras, "Extras"},
        { item_credits, "Credits" },
        { item_godmode, "God Mode"}
};

/**
 * @brief Main app
 * @return Not used
 */
int main(void){

    // Setup the system
    led_init();
    button_init();
    speaker_init();
    log_init();

    // Pop pop!
    beep(75, 600);
    nrf_delay_ms(50);
    beep(150, 800);
    nrf_delay_ms(50);

    // Timers
    app_timer_init();

    // BLE
    //gap_params_init();
    ble_stack_init();
    scan_start();

    // Init the display
    st7735_init();
	st7735_start();
	util_gfx_init();

    if(!util_sd_init()){
        util_sd_error();
    }

    // Init the random number generator
    nrf_drv_rng_init(NULL);

    // Setup the battery monitor
    adc_configure();
    adc_start();

    // Setup the UART
    uart_init();

    // Boot! Boot! Boot!
    printf("Booted!\n");
    // printf goes to the RTT_Terminal.log after you've fired up debug.sh

    util_gfx_draw_raw_file("BOOT.RAW", 0, 0, GFX_WIDTH, GFX_HEIGHT, bootCallback, false, NULL);

    setPowerUpLEDs(POWERUP_0);
    setLevelLEDs(LEVEL0);

    // Load the user
    loadUser();

    if(!user.configured){
        // Configure the system
        printf("First time setup\n");
        firstSetup();
    }

    // Init the WarGames game
    wg_Init();

    // Configure the systick
    sysTickStart();

    // Setup a timer for shutting down animations in standby
    app_timer_create(&standby_animation_timer_id, APP_TIMER_MODE_SINGLE_SHOT, standby_animation_timeout_handler);

    // Setup the BLE
    advertising_setUser(user.name);
    advertising_setClan(user.clan);
    advertising_setScore(user.score);

    ble_adv_start();

    setTempScoreModifier(0);

#pragma clang diagnostic push
#pragma clang diagnostic ignored "-Wmissing-noreturn"
    while(true) {

        util_gfx_fill_screen(COLOR_BLACK);

        drawScreenTemplate();

        // Draw the main menu

#ifdef GODMODE
        int subMenu = getMenuSelection(mainMenu, 50, ARRAY_SIZE(mainMenu), 4, 15000, true);
#else
        int subMenu = getMenuSelection(mainMenu, 50, ARRAY_SIZE(mainMenu) - 1, 4, 15000, true);
#endif

        switch(subMenu){
            case item_games:
                games();
                break;
            case item_nearby:
                nearby();
                break;
            case item_extras:
                extras();
                break;
            case item_credits:
                credits();
                break;
            case item_godmode:
                godMode();
                break;
            default:
                // Show the standby screen
                showStandby();
                break;
        }

    }
#pragma clang diagnostic pop

}

/**
 * Show the standby screen
 * @param p_context
 */
void showStandby(void){

    uint16_t nearbyCounter = 0;
    uint16_t animationCounter = 0;
    uint8_t delayCount = 0;
    drawStandby();

    while(true){
        if(getButton(false)){
            // User pressed a button
            return;
        }
        nrf_delay_ms(25);

        if(partyMode){
            // PARTYYYY!
            util_gfx_draw_raw_file("/EXTRAS/SHEEP6.RAW", 0, 0, GFX_WIDTH, GFX_HEIGHT, partyCallback, true, NULL);
        }

        if(sheepMode){
            // SHEEEEP
            do{
                uint8_t i;
                util_gfx_draw_raw_file("/EXTRAS/SHEEP1.RAW", 0, 0, GFX_WIDTH, GFX_HEIGHT, NULL, false, NULL);
                for(i = 0; i < 100; i++){
                    if(getButton(false)){
                        break;
                    }
                    nrf_delay_ms(25);
                }
                util_gfx_draw_raw_file("/EXTRAS/SHEEP2.RAW", 0, 0, GFX_WIDTH, GFX_HEIGHT, NULL, false, NULL);
                for(i = 0; i < 100; i++){
                    if(getButton(false)){
                        break;
                    }
                    nrf_delay_ms(25);
                }
                util_gfx_draw_raw_file("/EXTRAS/SHEEP3.RAW", 0, 0, GFX_WIDTH, GFX_HEIGHT, NULL, false, NULL);
                for(i = 0; i < 100; i++){
                    if(getButton(false)){
                        break;
                    }
                    nrf_delay_ms(25);
                }
                util_gfx_draw_raw_file("/EXTRAS/SHEEP4.RAW", 0, 0, GFX_WIDTH, GFX_HEIGHT, NULL, false, NULL);
                for(i = 0; i < 100; i++){
                    if(getButton(false)){
                        break;
                    }
                    nrf_delay_ms(25);
                }
                util_gfx_draw_raw_file("/EXTRAS/SHEEP5.RAW", 0, 0, GFX_WIDTH, GFX_HEIGHT, NULL, false, NULL);
                for(i = 0; i < 100; i++){
                    if(getButton(false)){
                        break;
                    }
                    nrf_delay_ms(25);
                }
                util_gfx_draw_raw_file("/EXTRAS/SHEEP6.RAW", 0, 0, GFX_WIDTH, GFX_HEIGHT, NULL, false, NULL);
                for(i = 0; i < 100; i++){
                    if(getButton(false)){
                        break;
                    }
                    nrf_delay_ms(25);
                }
            }while (!getButton(false));

        }

        if(animationCounter ++ > (15000 / 25)){
            // Show an animation

            uint8_t rand;
            nrf_drv_rng_rand(&rand, 1);

            char files[64][9];
            uint8_t numFiles = 0;

            memset(files, 0, sizeof(files));

            numFiles = getFiles(files, "/EXTRAS", 64);

            rand = rand % numFiles;

            app_timer_start(standby_animation_timer_id, APP_TIMER_TICKS(10000), NULL);

            char filename[21];
            snprintf(filename, 21, "/EXTRAS/%s.RAW", files[rand]);

            util_gfx_draw_raw_file(filename, 0, 0, GFX_WIDTH, GFX_HEIGHT, NULL, true, NULL);

            animationCounter = 0;

            drawStandby();

        }

        if(nearbyCounter++ > (5000 / 25)){
            // Draw a shout
            uint8_t rand;
            nrf_drv_rng_rand(&rand, 1);

            bool haveBadge = false;
            BADGE_ADV badge;
            rand = rand % getBadgeNum();

            if(getBadge(rand, &badge)){

                if(getBadgeIconFile(badge.group) != NULL) {
                    util_gfx_draw_raw_file(getBadgeIconFile(badge.group), 0, 0, GFX_WIDTH, GFX_HEIGHT, NULL, false, NULL);
                }
                else{
                    util_gfx_draw_raw_file("/GROUPS/MISSING.RAW", 0, 0, GFX_WIDTH, GFX_HEIGHT, NULL, false, NULL);

                    util_gfx_fill_rect(0, 0, GFX_WIDTH, 15, COLOR_BLACK);

                    uint16_t w, h;
                    char name[16];
                    util_gfx_set_font(FONT_VERAMONO_5PT);
                    util_gfx_get_text_bounds(getBadgeGroupName(badge.group), 0, 0, &w, &h);
                    util_gfx_set_cursor(64 - (w / 2), 2);

                    snprintf(name, 16, "%s", getBadgeGroupName(badge.group));
                    util_gfx_print(name);
                }

                for(int i = 0; i < 10; i++){
                    if(i % 2 == 0) {
                        setPowerUpLEDs(POWERUP_4);
                        setLevelLEDs(LEVEL0);
                    }
                    else{
                        setPowerUpLEDs(POWERUP_0);
                        setLevelLEDs(LEVEL4);
                    }

                    delayCount = 0;
                    while(delayCount++ < 10) {
                        if(getButton(false)){
                            setPowerUpLEDs(POWERUP_0);
                            setLevelLEDs(LEVEL0);
                            return;
                        }
                        nrf_delay_ms(25);
                    }
                }
                setPowerUpLEDs(POWERUP_0);
                setLevelLEDs(LEVEL0);

                delayCount = 0;
                while(delayCount++ < 40) {
                    if(getButton(false)){
                        return;
                    }
                    nrf_delay_ms(25);
                }

                drawStandby();
            }

            nearbyCounter = 0;

        }
    }

}

/**
 * Draw the user stats on the standby screen
 */
void drawStandby(void){

    // Setup the main screen
    util_gfx_fill_screen(COLOR_BLACK);

    // Show the username
    util_gfx_set_font(FONT_MONO55_8PT);
    util_gfx_set_color(COLOR_WHITE);

    uint16_t w, h;
    util_gfx_get_text_bounds(user.name, 0, 0, &w, &h);
    util_gfx_set_cursor(64 - (w / 2), 2);
    util_gfx_print(user.name);

    util_gfx_set_font(FONT_GAMEPLAY_5PT);
    util_gfx_set_color(COLOR_BLUE);
    util_gfx_set_cursor(2, 20);

    char score[11];
    snprintf(score, 11, "%u", user.score);
    util_gfx_print(score);

    char modifier[6];
    if(getTotalScoreModifier() > 0){
        util_gfx_set_color(COLOR_GREEN);
    }
    if(getTotalScoreModifier() == 0){
        util_gfx_set_color(COLOR_WHITE);
    }
    if(getTotalScoreModifier() < 0){
        util_gfx_set_color(COLOR_RED);
    }
    snprintf(modifier, 6, "%+d", getTotalScoreModifier());
    util_gfx_get_text_bounds(modifier, 0, 0, &w, &h);
    util_gfx_set_cursor(GFX_WIDTH - w - 1, 20);
    util_gfx_print(modifier);

    util_gfx_draw_raw_file(getClanFile(user.clan), 0, 29, GFX_WIDTH, 100, NULL, false, NULL);

}


/**
 * Configure a new user
 */
void firstSetup(void){

    // Clear out the user data
    memset(&user, 0, sizeof(USER));

    util_gfx_fill_screen(COLOR_BLACK);
    util_gfx_set_font(FONT_COMPUTER_12PT);
    util_gfx_set_color(COLOR_BLUE);
    util_gfx_set_cursor(20, 0);
    util_gfx_print("Welcome");

    util_gfx_set_font(FONT_MONO55_8PT);
    util_gfx_set_color(COLOR_WHITE);
    util_gfx_set_cursor(5, 20);
    util_gfx_print("Can you get the\n highest score?");


    util_gfx_set_cursor(28, 65);
    util_gfx_print("Let's get\n    started");

    util_gfx_set_cursor(35, 110);
    util_gfx_print("Press A");

    while(getButton(false) != USER_BUTTON_A){
        // Wait until pressed
    }
    while(getButton(false) == USER_BUTTON_A){
        // Wait until released
    }

    util_gfx_fill_rect(0, 18, 128, 88, COLOR_BLACK);
    util_gfx_set_cursor(8, 20);
    util_gfx_print("You can change\n later and your\n score will be\n     kept");


    while(getButton(false) != USER_BUTTON_A){
        // Wait until pressed
    }
    while(getButton(false) == USER_BUTTON_A){
        // Wait until released
    }

    util_gfx_fill_rect(0, 18, 128, 88, COLOR_BLACK);
    util_gfx_set_cursor(18, 20);
    util_gfx_print("You play for\n  yourself and\n   your clan");


    while(getButton(false) != USER_BUTTON_A){
        // Wait until pressed
    }
    while(getButton(false) == USER_BUTTON_A){
        // Wait until released
    }

    util_gfx_fill_rect(0, 18, 128, 88, COLOR_BLACK);
    util_gfx_set_cursor(5, 20);
    util_gfx_print("Scoreboard will\n   be at the\n     party");

    while(getButton(false) != USER_BUTTON_A){
        // Wait until pressed
    }
    while(getButton(false) == USER_BUTTON_A){
        // Wait until released
    }


    userConfigure();

}


typedef enum {
    game_invaders,
    game_snake,
    game_pips_the_et,
    game_tic_tac_toe,
    NUM_MENU_GAMES_ITEMS
} MENU_GAMES;


MENU gameMenu[NUM_MENU_GAMES_ITEMS] = {
        { game_invaders, "Invaders" },
        { game_snake, "Snake" },
        { game_pips_the_et, "Pips the ET" },
        { game_tic_tac_toe, "TicTacToe" }
};


/**
 * Show the games menu
 */
void games(void){

    drawScreenTemplate();

    int retScore = 0;
    int getGame;
    if(user.wargameUnlock) {
        getGame = getMenuSelection(gameMenu, 50, ARRAY_SIZE(gameMenu), 4, 15000, true);
    }
    else{
        getGame = getMenuSelection(gameMenu, 50, ARRAY_SIZE(gameMenu) , 4, 15000, true);

    }

    switch(getGame){
        case game_invaders:
            // Space invaders
            retScore = SpaceInvaders();
            break;
        case game_snake:
            // Snake run
            retScore = Snake();
            break;
        case game_pips_the_et:
            retScore = PipsTheET();
            break;
        case game_tic_tac_toe:
            retScore = TicTacToe();
            break;
        default:
            break;
    }


    // Figure out the score modifier
    retScore = retScore + (retScore * ((getTotalScoreModifier() / 100)));

    // Calculate the user's score
    if(user.score + retScore > 0){
        user.score += retScore;
    }
    else{
        user.score = 0;
    }

    storeUser();
    advertising_setScore(user.score);

}




typedef enum {
    extra_reconfig,
    extra_boot,
    extra_groups,
    extra_fun,
    extra_version,
    NUM_MENU_EXTRA_ITEMS
} MENU_EXTRA;


MENU extraMenu[NUM_MENU_EXTRA_ITEMS] = {
        { extra_reconfig, "Reconfig" },
        { extra_boot, "Boot Logo" },
        { extra_groups, "DC Groups" },
        { extra_fun, "Fun Stuff" },
        { extra_version, "Version" }
};

/**
 * Show the extras menu
 */
void extras(void){

    drawScreenTemplate();

    int getExtra = getMenuSelection(extraMenu, 50, ARRAY_SIZE(extraMenu), 4, 15000, true);

    switch(getExtra){
        case extra_reconfig:
            util_gfx_set_font(FONT_MONO55_8PT);
            util_gfx_set_color(COLOR_WHITE);
            userConfigure();
            break;
        case extra_boot:
            util_gfx_draw_raw_file("BOOT.RAW", 0, 0, GFX_WIDTH, GFX_HEIGHT, bootCallback, false, NULL);
            setPowerUpLEDs(POWERUP_0);
            setLevelLEDs(LEVEL0);
            break;
        case extra_groups:
            extraShowGroups();
            break;
        case extra_fun:
            extraFunBrowser();
            break;
        case extra_version:
            extraVersion();
            break;
        default:
            break;
    }

}

/**
 * Show the credits
 */
void credits(void){

    util_gfx_draw_raw_file("CREDITS.RAW", 0, 0, GFX_WIDTH, GFX_HEIGHT, NULL, false, NULL);

    while(true){
        if(getButton(false)){
            // User pressed a button
            return;
        }
        nrf_delay_ms(10);
    }

}

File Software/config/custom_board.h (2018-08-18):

/**
 *
 * @file custom_board.h
 *
 * @date May 24, 2017
 * @author hamster
 *
 * This is the custom board defines for the LEDs and etc on the DC25 badge
 *
 */

#ifndef DC801_H
#define DC801_H

#ifdef __cplusplus
extern "C" {
#endif

// LEDs definitions

// Low is active
#define LEDS_ACTIVE_STATE 0

#define VOLTAGE_SENSE		4

// LED Pins

#define LED_LEVEL_UP_0     	30
#define LED_LEVEL_UP_1     	29
#define LED_LEVEL_UP_2     	28
#define LED_LEVEL_UP_3		25

#define LED_POWER_UP_0  	2
#define LED_POWER_UP_1      1
#define LED_POWER_UP_2      0
#define LED_POWER_UP_3		31

// Arrays to make iteration easy
// The Nordic SDK uses LEDS_LIST internally
#define LEDS_LIST { \
		LED_LEVEL_UP_0, 	\
		LED_LEVEL_UP_1, 	\
		LED_LEVEL_UP_2,	\
		LED_LEVEL_UP_3,	\
		LED_POWER_UP_0,	\
		LED_POWER_UP_1,	\
		LED_POWER_UP_2,	\
		LED_POWER_UP_3	}

#define LEDS_NUMBER    		8

//static const uint32_t led_list[LEDS_NUMBER] = LEDS_LIST;

#define LEVEL_UP_LEDS_LIST { \
		LED_LEVEL_UP_0, 	\
		LED_LEVEL_UP_1, 	\
		LED_LEVEL_UP_2,	\
		LED_LEVEL_UP_3	}

#define LEVEL_UP_LEDS_NUMBER    		4

static const uint32_t level_up_led_list[LEVEL_UP_LEDS_NUMBER] = LEVEL_UP_LEDS_LIST;

#define POWER_UP_LEDS_LIST { \
		LED_POWER_UP_0, 	\
		LED_POWER_UP_1, 	\
		LED_POWER_UP_2,	\
		LED_POWER_UP_3	}

#define POWER_UP_LEDS_NUMBER    		4

static const uint32_t power_up_led_list[POWER_UP_LEDS_NUMBER] = POWER_UP_LEDS_LIST;

// Push buttons

#define BUTTONS_NUMBER 6


#define USER_BUTTON_NONE		0
#define USER_BUTTON_UP      	17
#define USER_BUTTON_DOWN       	19
#define USER_BUTTON_LEFT       	20
#define USER_BUTTON_RIGHT       18
#define USER_BUTTON_A			27
#define USER_BUTTON_B			26

#define LONG_PRESS_MASK		0x8000

#define USER_BUTTON_UP_LONG    	(17  | LONG_PRESS_MASK)
#define USER_BUTTON_DOWN_LONG   (19  | LONG_PRESS_MASK)
#define USER_BUTTON_LEFT_LONG   (20 | LONG_PRESS_MASK)
#define USER_BUTTON_RIGHT_LONG  (18 | LONG_PRESS_MASK)
#define USER_BUTTON_A_LONG		(27  | LONG_PRESS_MASK)
#define USER_BUTTON_B_LONG		(26 | LONG_PRESS_MASK)

#define BUTTONS_LIST { \
		USER_BUTTON_UP,	\
		USER_BUTTON_DOWN,	\
		USER_BUTTON_LEFT,	\
		USER_BUTTON_RIGHT,	\
		USER_BUTTON_A,		\
		USER_BUTTON_B	}

// Low is active
#define BUTTONS_ACTIVE_STATE	0
// Don't need a pull up
#define BUTTON_PULL				0

#define BSP_BUTTON_0   USER_BUTTON_UP
#define BSP_BUTTON_1   USER_BUTTON_DOWN
#define BSP_BUTTON_2   USER_BUTTON_LEFT
#define BSP_BUTTON_3   USER_BUTTON_RIGHT

#define RX_PIN_NUMBER  6
#define TX_PIN_NUMBER  8
#define CTS_PIN_NUMBER NRF_UART_PSEL_DISCONNECTED
#define RTS_PIN_NUMBER NRF_UART_PSEL_DISCONNECTED
#define HWFC           false

#define BUTTON_PRESSED 	0

// Just one speaker
#define SPEAKER		24

// LCD
// The SPI ports are defined in the config/sdk_config.h
#define LCD_RESET	9
#define LCD_LIGHT	5

// Clock
// Low frequency clock source to be used by the SoftDevice
// We're using the internal RC osc
#define NRF_CLOCK_LFCLKSRC      {.source        = NRF_CLOCK_LF_SRC_RC, \
                                 .rc_ctiv       = 16, \
                                 .rc_temp_ctiv  = 2, \
                                 .xtal_accuracy = NRF_CLOCK_LF_XTAL_ACCURACY_20_PPM}


#ifdef __cplusplus
}
#endif

#endif // DC801_H

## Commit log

2018-08-18 Publishing the design files for the DC801 DC26 badge
    [01_tactile_push_boton_B3S-1000_newark_52F3560.SLDPRT, 01_tactile_push_boton_B3S-1000_newark_52F3560.STEP, 473521001_microSD.step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]
2019-08-29 Adding pdf export of the schematic

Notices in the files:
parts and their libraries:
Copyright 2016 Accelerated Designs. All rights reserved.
